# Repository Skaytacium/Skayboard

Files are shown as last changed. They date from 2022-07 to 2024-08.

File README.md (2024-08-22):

# Skayboard

## What?

Its **Skay**tacium's key**board**.

## Why? (I get this one a lot)

Good question.

## Layout?

[Here](http://www.keyboard-layout-editor.com/#/gists/023afb41bbd40c8d3c89d3bae84d59ea).

## Really, why?

I couldn't find a keyboard which had this exact layout (some suggested a 60% + numpad, do you think I'm sensible?).  
I also found the pre-existing PCBs too expensive and the open source ones had goofy layouts.  
I'm jobless, stupid and I regret everything.

## And?

- The `sk` keys are macro keys.
- It uses [QMK](https://qmk.fm/).
- Uses [SK6812 Mini-E](https://cdn-shop.adafruit.com/product-files/4960/4960_SK6812MINI-E_REV02_EN.pdf) LEDs, hand solder them if you want to, connection matrix [here](#connections) (because the name starts with SK).
+ The Skaytacium way to build one would be:
  - C<sup>3</sup>Equalz Tangerines, light green (52g)
  - 5mm acrylic plate
  - Stacked crylic and aluminum (layered)
- It took me ~~2~~ 3 years to make this (check earliest commit) because of the global chip shortage and doomerism.

## Details?

### PCB?
- 2 layer
- 355x107 mm
- AVR (32U4), keeping it as simple as possible.
	+ There is no ESD, overcurrent or surge protection on the PCB. I assume all modern electronic USB ports to compensate for that.
- Pads made for handsoldering.
- Curved traces, because the 90s were cool.
- **Not attached to the case in any way, only to the plate, allows for more customizable mounting options.**
- `svg` and `dxf` files for reference are in `lib/gen`.

#### Renders?
- Front
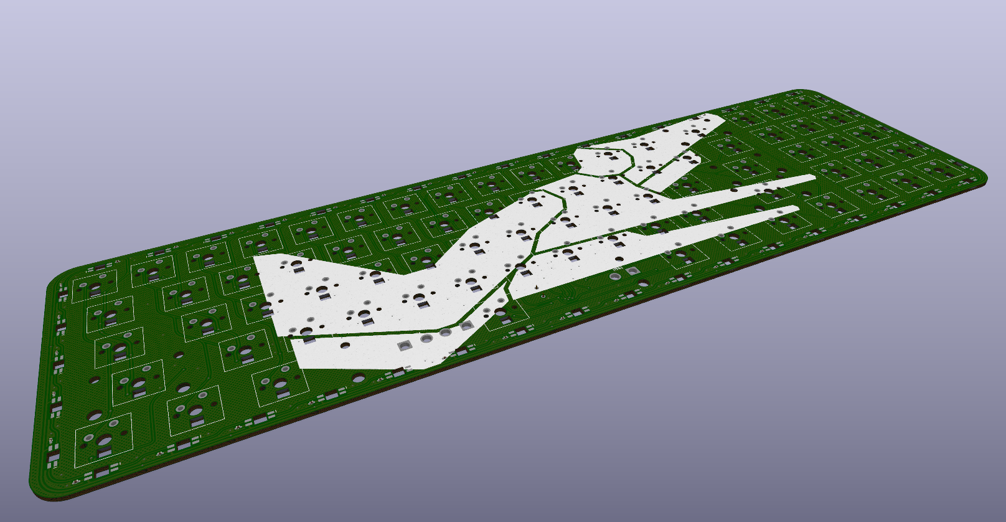
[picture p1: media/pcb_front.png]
pcb front

- Back
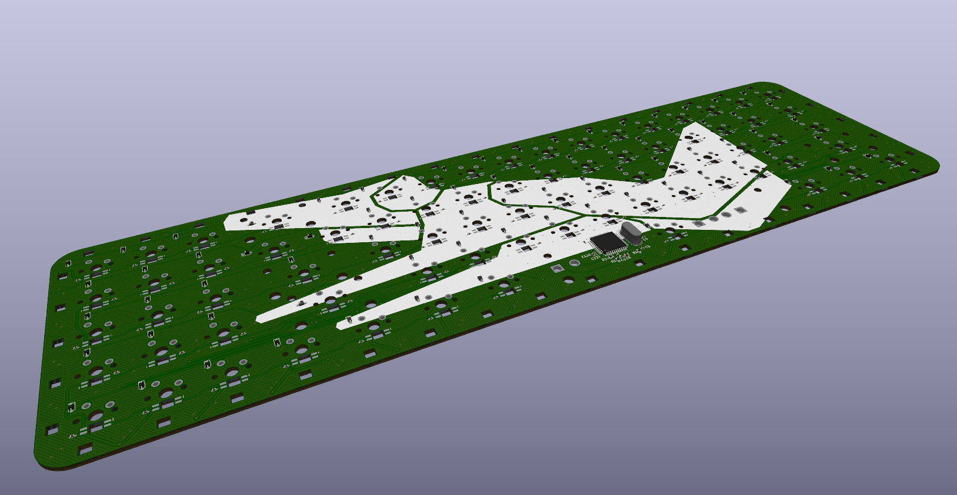
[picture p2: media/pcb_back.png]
pcb back

- Front populated
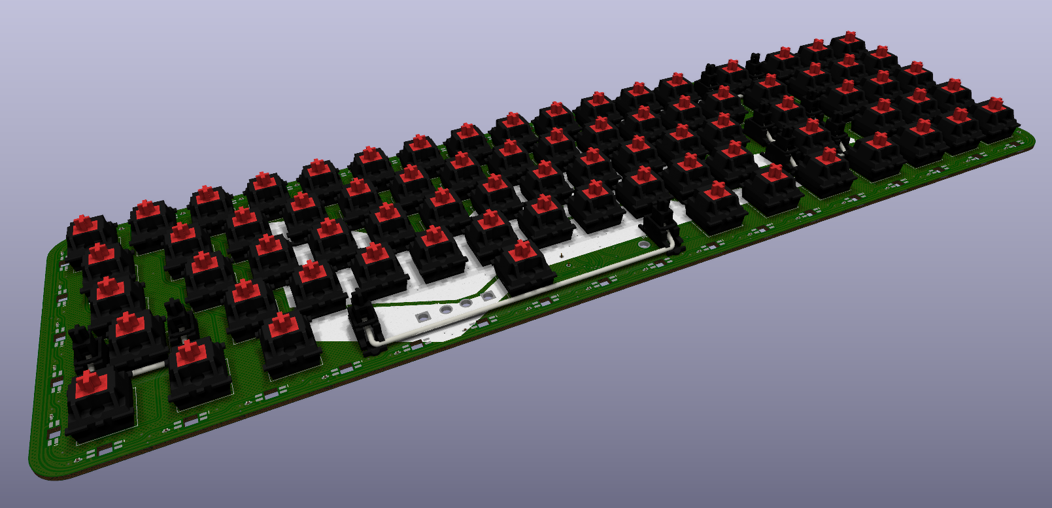
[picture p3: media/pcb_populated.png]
pcb populated


### Plate?
- Desgined for 5mm plates, but can be used for 3mm-5mm.
	+ 1.5mm should also be possible, but it is strongly not recommended to use that.
- Who am I to tell you though, go crazy with it, `dxf` file is in `lib/gen`.

#### Renders?
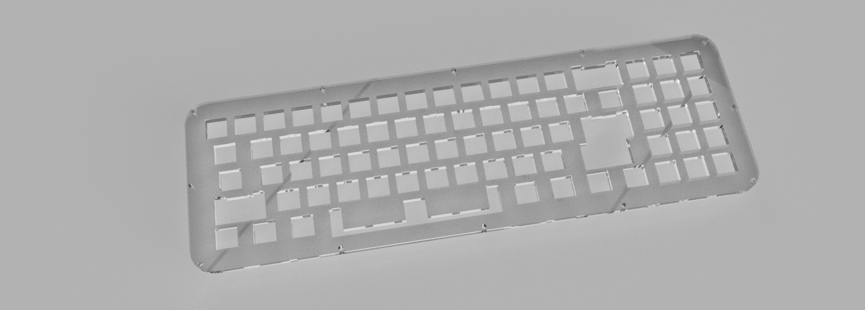
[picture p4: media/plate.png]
plate


### Case?
- Stacked in the following order:
	+ Spacer (L2)
	+ Plate (PCB has no connection to the case)
	+ Spacer (L1)
	+ Spacer (L0)
	+ Case & Logo
- **IMPORTANT:** Spacers L1 and L0 should have atleast 6mm of total height due to the oscillator being an HC49, and that requires 4mm clearance + 1.6mm clearance for PCB thickness.
- **ALSO IMPORTANT:** Either one of spacers L1 or L0 have to be transparent, otherwise you won't be able to see the underglow LEDs (duh). But again, go crazy with it.
- **ALSO SERIOUSLY IMPORTANT:** The `dxf` files do not contain holes for threading, even though the renders show that, you'll have to choose your method of connection, i.e. glue or self-drilled screws. 
- Case & Logo are a single layer since the logo is just an inverse of the case cutout.
- All `dxf` files are in `lib/gen`.

#### Renders?
- Case & Logo
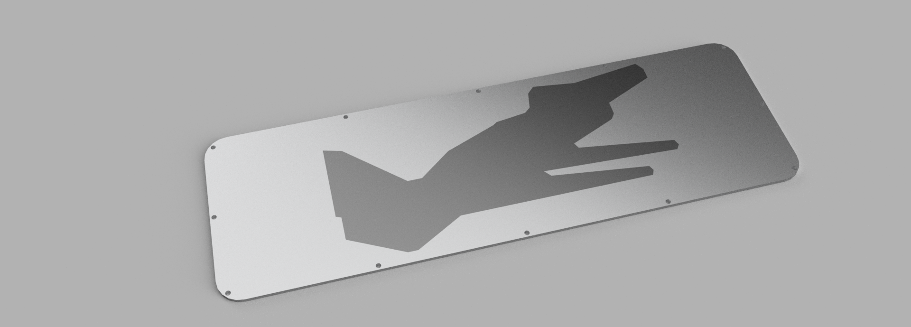
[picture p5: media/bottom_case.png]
case and logo

- Full case
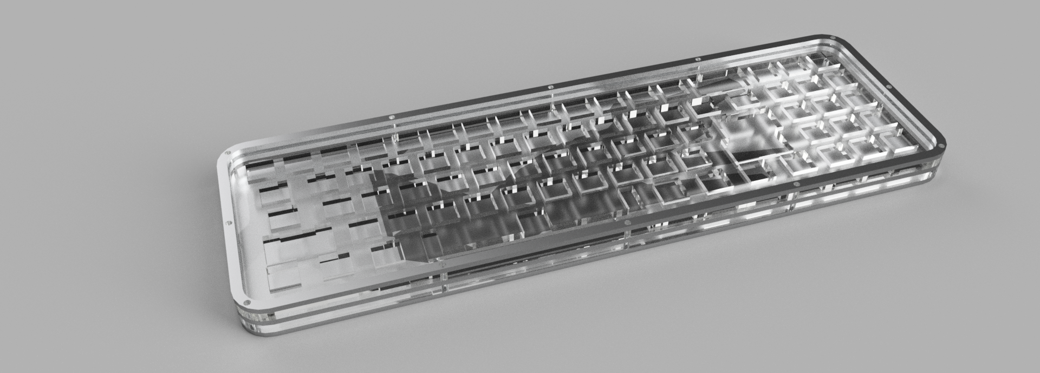
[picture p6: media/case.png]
case


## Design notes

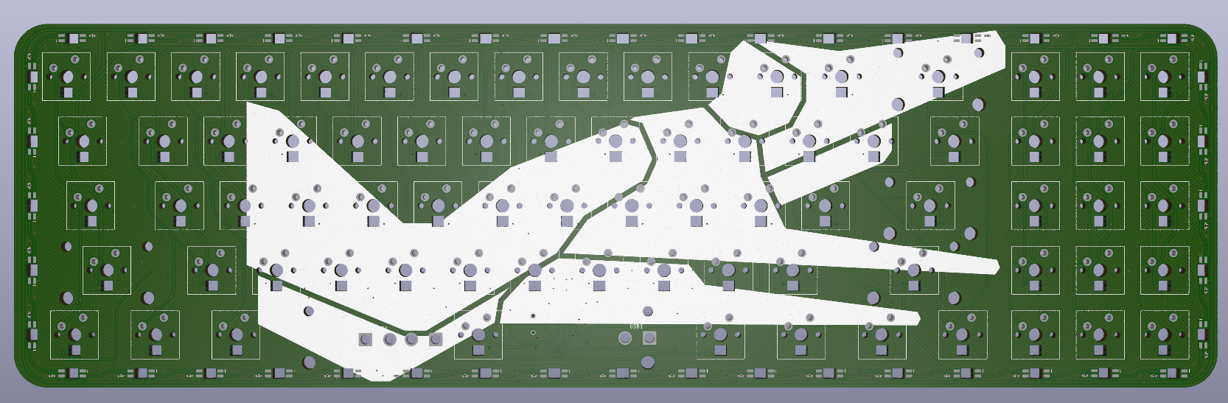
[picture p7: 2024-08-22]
media/pcb_top.png

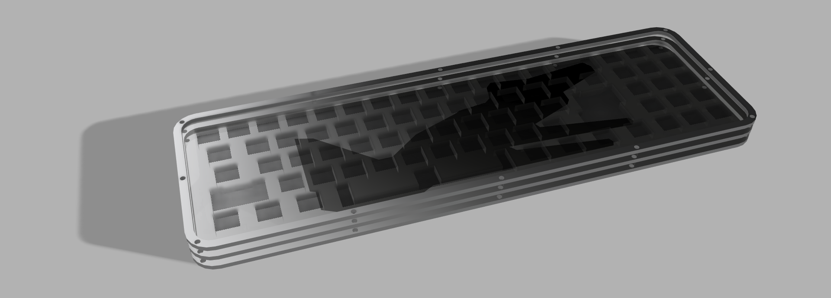
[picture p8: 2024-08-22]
media/case_front.png

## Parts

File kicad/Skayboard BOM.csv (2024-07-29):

Reference | Value | Datasheet | Footprint | Qty | DNP
C1,C6,C7,C8,C9,C10,C11,C12,C13,C14,C15,C16,C17,C18,C19,C20,C21,C22,C23,C24,C25,C26,C27,C28,C29,C30,C31,C32,C33,C34,C35,C36,C37,C38,C39,C40,C41,C42,C43,C44,C45,C46,C47,C48,C49,C50,C51,C52,C53,C54,C55,C56,C57,C58,C59,C60,C61,C62,C63,C64,C65,C66,C67,C68,C69,C70,C71,C72,C73,C74,C75,C76,C77,C78,C79,C80,C81,C82,C83,C84,C85,C86,C87,C88,C89,C90,C91,C92,C93,C94,C95,C96,C97,C98,C99,C100,C101,C102,C103,C104,C105,C106,C107,C108,C109,C110,C111,C112,C113,C114,C115,C116,C117,C118,C119,C120,C121,C122,C123,C124,C125,C126,C127,C128 | 100nF | ~ | Capacitor_SMD:C_0402_1005Metric_Pad0.74x0.62mm_HandSolder | 124
C2,C4 | 22pF | ~ | Capacitor_SMD:C_0402_1005Metric_Pad0.74x0.62mm_HandSolder | 2
C3 | 1uF | ~ | Capacitor_SMD:C_0603_1608Metric_Pad1.08x0.95mm_HandSolder | 1
C5 | 10uF | ~ | Capacitor_SMD:C_0603_1608Metric_Pad1.08x0.95mm_HandSolder | 1
D1,D2,D3,D4,D5,D6,D7,D8,D9,D10,D11,D12,D13,D14,D15,D16,D17,D18,D19,D20,D21,D22,D23,D24,D25,D26,D27,D28,D29,D30,D31,D32,D33,D34,D35,D36,D37,D38,D39,D40,D41,D42,D43,D44,D45,D46,D47,D48,D49,D50,D51,D52,D53,D54,D55,D56,D57,D58,D59,D60,D61,D62,D63,D64,D65,D66,D67,D68,D69,D70,D71,D72,D73,D74,D75,D76 | 1N4148WS | https://www.vishay.com/docs/85751/1n4148ws.pdf | Diode_SMD:D_SOD-323_HandSoldering | 76
LED1,LED2,LED3,LED4,LED5,LED6,LED7,LED8,LED9,LED10,LED11,LED12,LED13,LED14,LED15,LED16,LED17,LED18,LED19,LED20,LED21,LED22,LED23,LED24,LED25,LED26,LED27,LED28,LED29,LED30,LED31,LED32,LED33,LED34,LED35,LED36,LED37,LED38,LED39,LED40,LED41,LED42,LED43,LED44,LED45,LED46,LED47,LED48,LED49,LED50,LED51,LED52,LED53,LED54,LED55,LED56,LED57,LED58,LED59,LED60,LED61,LED62,LED63,LED64,LED65,LED66,LED67,LED68,LED69,LED70,LED71,LED72,LED73,LED74,LED75,LED76,LED77,LED78,LED79,LED80,LED81,LED82,LED83,LED84,LED85,LED86,LED87,LED88,LED89,LED90,LED91,LED92,LED93,LED94,LED95,LED96,LED97,LED98,LED99,LED100,LED101,LED102,LED103,LED104,LED105,LED106,LED107,LED108,LED109,LED110,LED111,LED112,LED113,LED114,LED115,LED116,LED117,LED118,LED119,LED120 | SK6812MINI-E | https://cdn-shop.adafruit.com/product-files/4960/4960_SK6812MINI-E_REV02_EN.pdf | Skayboard:SK6812MINI-E | 120 | DNP
POWER1,RST1,USB1 | Conn_01x02 | ~ | Connector_Wire:SolderWire-2.5sqmm_1x02_P7.2mm_D2.4mm_OD3.6mm | 3 | DNP
R1 | 10K | ~ | Resistor_SMD:R_0603_1608Metric_Pad0.98x0.95mm_HandSolder | 1
R2,R3 | 22 | ~ | Resistor_SMD:R_0603_1608Metric_Pad0.98x0.95mm_HandSolder | 2
U1 | ATmega32U4-A | http://ww1.microchip.com/downloads/en/DeviceDoc/Atmel-7766-8-bit-AVR-ATmega16U4-32U4_Datasheet.pdf | Package_QFP:TQFP-44_10x10mm_P0.8mm | 1
Y1 | 16MHz | ~ | Crystal:Crystal_HC49-U_Vertical | 1

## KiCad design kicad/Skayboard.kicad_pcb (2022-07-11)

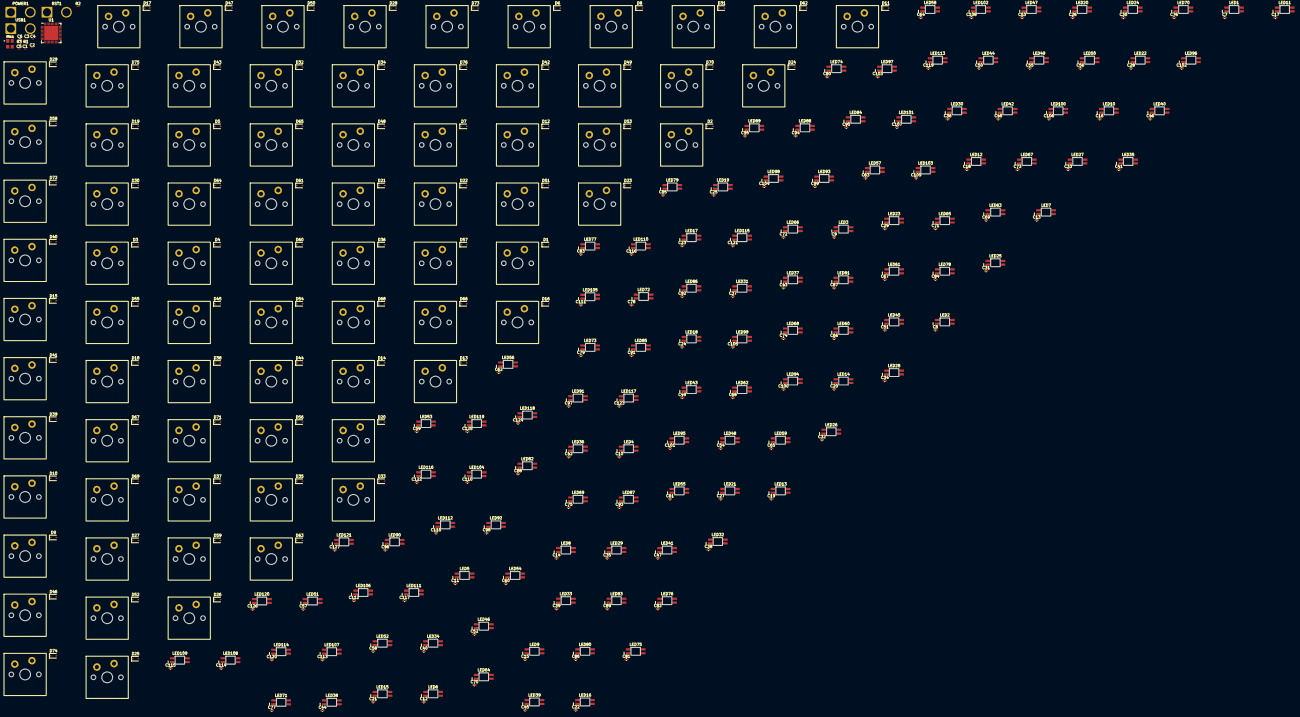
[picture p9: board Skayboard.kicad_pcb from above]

Board: 2 copper layers, 408 parts (0 on the bottom side), 153 nets, no tracks yet.

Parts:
C1, C2, C3, C4: 22pF; C_01005_0402Metric
C5: 100nF; C_01005_0402Metric
C6, C7, C8, C9, C10, C11, C12, C13, C14, C15, C16, C17, C18, C19, C20, C21, C22, C23, C24, C25, C26, C27, C28, C29, C30, C31, C32, C33, C34, C35, C36, C37, C38, C39, C40, C41, C42, C43, C44, C45, C46, C47, C48, C49, C50, C51, C52, C53, C54, C55, C56, C57, C58, C59, C60, C61, C62, C63, C64, C65, C66, C67, C68, C69, C70, C71, C72, C73, C74, C75, C76, C77, C78, C79, C80, C81, C82, C83, C84, C85, C86, C87, C88, C89, C90, C91, C92, C93, C94, C95, C96, C97, C98, C99, C100, C101, C102, C103, C104, C105, C106, C107, C108, C109, C110, C111, C112, C113, C114, C115, C116, C117, C118, C119, C120, C121, C122, C123, C124, C125, C126, C127: 100nF; C_0402_1005Metric
D1, D2, D3, D4, D5, D6, D7, D8, D9, D10, D11, D12, D13, D14, D15, D16, D17, D18, D19, D20, D21, D22, D23, D24, D25, D26, D27, D28, D29, D30, D31, D32, D33, D34, D35, D36, D37, D38, D39, D40, D41, D42, D43, D44, D45, D46, D47, D48, D49, D50, D51, D52, D53, D54, D55, D56, D57, D58, D59, D60, D61, D62, D63, D64, D65, D66, D67, D68, D69, D70, D71, D72, D73, D74, D75, D76: 1N4148WS; D_SOD-323
LED1, LED2, LED3, LED4, LED5, LED6, LED7, LED8, LED9, LED10, LED11, LED12, LED13, LED14, LED15, LED16, LED17, LED18, LED19, LED20, LED21, LED22, LED23, LED24, LED25, LED26, LED27, LED28, LED29, LED30, LED31, LED32, LED33, LED34, LED35, LED36, LED37, LED38, LED39, LED40, LED41, LED42, LED43, LED44, LED45, LED46, LED47, LED48, LED49, LED50, LED51, LED52, LED53, LED54, LED55, LED56, LED57, LED58, LED59, LED60, LED61, LED62, LED63, LED64, LED65, LED66, LED67, LED68, LED69, LED70, LED71, LED72, LED73, LED74, LED75, LED76, LED77, LED78, LED79, LED80, LED81, LED82, LED83, LED84, LED85, LED86, LED87, LED88, LED89, LED90, LED91, LED92, LED93, LED94, LED95, LED96, LED97, LED98, LED99, LED100, LED101, LED102, LED103, LED104, LED105, LED106, LED107, LED108, LED109, LED110, LED111, LED112, LED113, LED114, LED115, LED116, LED117, LED118, LED119, LED120, LED121: SK6812MINI-E
MX1, MX2, MX3, MX4, MX5, MX6, MX7, MX8, MX9, MX10, MX11, MX12, MX13, MX14, MX15, MX16, MX17, MX18, MX19, MX20, MX21, MX22, MX23, MX24, MX25, MX26, MX27, MX28, MX29, MX30, MX31, MX32, MX33, MX34, MX35, MX36, MX37, MX38, MX39, MX40, MX41, MX42, MX43, MX44, MX45, MX46, MX47, MX48, MX49, MX50, MX51, MX52, MX53, MX54, MX55, MX56, MX57, MX58, MX59, MX60, MX61, MX62, MX63, MX64, MX65, MX66, MX67, MX68, MX69, MX70, MX71, MX72, MX73, MX74, MX75, MX76: MX
POWER1: Conn_01x02; SolderWire-2.5sqmm_1x02_P7.2mm_D2.4mm_OD3.6mm
R1, R2: 22; R_0201_0603Metric
R3: 10K; R_0201_0603Metric
RST1: Conn_01x02; SolderWire-2.5sqmm_1x02_P7.2mm_D2.4mm_OD3.6mm
U1: ATmega32U4-M; QFN-44-1EP_7x7mm_P0.5mm_EP5.2x5.2mm
USB1: Conn_01x02; SolderWire-2.5sqmm_1x02_P7.2mm_D2.4mm_OD3.6mm
XTAL1: X322516MLB4SI; OSC_X322516MLB4SI

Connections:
/0/DIN: LED10.2 (DOUT), LED11.4 (DIN)
/1/DIN: LED1.2 (DOUT), LED2.4 (DIN)
/1/DOUT: LED2.2 (DOUT), LED3.4 (DIN)
/2/DOUT: LED3.2 (DOUT), LED4.4 (DIN)
/3/DOUT: LED4.2 (DOUT), LED5.4 (DIN)
/4/DOUT: LED5.2 (DOUT), LED6.4 (DIN)
/5/DOUT: LED6.2 (DOUT), LED7.4 (DIN)
/6/DOUT: LED7.2 (DOUT), LED8.4 (DIN)
/7/DOUT: LED8.2 (DOUT), LED9.4 (DIN)
/8/DOUT: LED9.2 (DOUT), LED10.4 (DIN)
/"/DIN: LED49.2 (DOUT), LED50.4 (DIN)
/"/DOUT: LED50.2 (DOUT), LED52.4 (DIN)
/,/DIN: LED67.4 (DIN), LED68.2 (DOUT)
/,/DOUT: LED66.4 (DIN), LED67.2 (DOUT)
/-/DIN: LED11.2 (DOUT), LED12.4 (DIN)
/-/DOUT: LED12.2 (DOUT), LED13.4 (DIN)
/./DIN: LED68.4 (DIN), LED69.2 (DOUT)
/;/DIN: LED48.2 (DOUT), LED49.4 (DIN)
/=/DOUT: LED13.2 (DOUT), LED14.4 (DIN)
/A/DIN: LED40.4 (DIN), LED80.2 (DOUT)
/A/DOUT: LED40.2 (DOUT), LED41.4 (DIN)
/B Slash/DIN: LED33.4 (DIN), LED34.2 (DOUT)
/B Slash/DOUT: LED32.4 (DIN), LED33.2 (DOUT)
/B/DIN: LED64.4 (DIN), LED65.2 (DOUT)
/B/DOUT: LED63.4 (DIN), LED64.2 (DOUT)
/Bksp/DOUT: LED14.2 (DOUT), LED15.4 (DIN)
/C/DIN: LED62.4 (DIN), LED63.2 (DOUT)
/C/DOUT: LED61.4 (DIN), LED62.2 (DOUT)
/COL^{0}: MX1.1 (COL), MX18.1 (COL), MX35.1 (COL), MX51.1 (COL), MX66.1 (COL), U1.18 (PD0)
/COL^{1}: MX2.1 (COL), MX19.1 (COL), MX36.1 (COL), MX52.1 (COL), MX67.1 (COL), U1.19 (PD1)
/COL^{2}: MX3.1 (COL), MX20.1 (COL), MX37.1 (COL), MX53.1 (COL), MX68.1 (COL), U1.20 (PD2)
/COL^{3}: MX4.1 (COL), MX21.1 (COL), MX38.1 (COL), MX54.1 (COL), U1.21 (PD3)
/COL^{4}: MX5.1 (COL), MX22.1 (COL), MX39.1 (COL), MX55.1 (COL), U1.22 (PD5)
/COL^{5}: MX6.1 (COL), MX23.1 (COL), MX40.1 (COL), MX56.1 (COL), MX69.1 (COL), U1.25 (PD4)
/COL^{6}: MX7.1 (COL), MX24.1 (COL), MX41.1 (COL), MX57.1 (COL), U1.37 (PF6)
/COL^{7}: MX8.1 (COL), MX25.1 (COL), MX42.1 (COL), MX58.1 (COL), U1.38 (PF5)
/COL^{8}: MX9.1 (COL), MX26.1 (COL), MX43.1 (COL), MX59.1 (COL), U1.39 (PF4)
/COL^{9}: MX10.1 (COL), MX27.1 (COL), MX44.1 (COL), MX60.1 (COL), MX70.1 (COL), U1.40 (PF1)
/COL^{10}: MX11.1 (COL), MX28.1 (COL), MX45.1 (COL), MX61.1 (COL), MX71.1 (COL), U1.41 (PF0)
/COL^{11}: MX12.1 (COL), MX29.1 (COL), MX46.1 (COL), MX62.1 (COL), MX72.1 (COL), U1.1 (PE6)
/COL^{12}: MX13.1 (COL), MX30.1 (COL), MX47.1 (COL), U1.8 (PB0)
/COL^{13}: MX14.1 (COL), MX31.1 (COL), MX73.1 (COL), U1.9 (PB1)
/COL^{14}: MX15.1 (COL), MX32.1 (COL), MX48.1 (COL), MX63.1 (COL), MX74.1 (COL), U1.10 (PB2)
/COL^{15}: MX16.1 (COL), MX33.1 (COL), MX49.1 (COL), MX64.1 (COL), MX75.1 (COL), U1.11 (PB3)
/COL^{16}: MX17.1 (COL), MX34.1 (COL), MX50.1 (COL), MX65.1 (COL), MX76.1 (COL), U1.12 (PB7)
/Caps/DIN: LED39.2 (DOUT), LED80.4 (DIN)
/D/DIN: LED41.2 (DOUT), LED42.4 (DIN)
/D/DOUT: LED42.2 (DOUT), LED43.4 (DIN)
/Del/DIN: LED34.4 (DIN), LED35.2 (DOUT)
/Down/DIN: LED100.2 (DOUT), LED101.4 (DIN)
/Down/DOUT: LED101.2 (DOUT), LED103.4 (DIN)
/E/DIN: LED23.4 (DIN), LED24.2 (DOUT)
/E/DOUT: LED22.4 (DIN), LED23.2 (DOUT)
/End/DIN: LED35.4 (DIN), LED37.2 (DOUT)
/Enter/DOUT: LED52.2 (DOUT), LED54.4 (DIN)
/Esc/DIN: LED1.4 (DIN), LED20.2 (DOUT)
/F Slash/DIN: LED69.4 (DIN), LED70.2 (DOUT)
/F/DOUT: LED43.2 (DOUT), LED44.4 (DIN)
/G/DOUT: LED44.2 (DOUT), LED45.4 (DIN)
/H/DOUT: LED45.2 (DOUT), LED46.4 (DIN)
/Home/DIN: LED15.2 (DOUT), LED16.4 (DIN)
/Home/DOUT: LED16.2 (DOUT), LED18.4 (DIN)
/I/DIN: LED28.4 (DIN), LED29.2 (DOUT)
/I/DOUT: LED27.4 (DIN), LED28.2 (DOUT)
/J/DOUT: LED46.2 (DOUT), LED47.4 (DIN)
/K/DOUT: LED47.2 (DOUT), LED48.4 (DIN)
/L Alt/DIN: LED81.2 (DOUT), LED83.4 (DIN)
/L Alt/DOUT: LED83.2 (DOUT), LED87.4 (DIN)
/L Ctrl/DOUT: LED59.2 (DOUT), LED81.4 (DIN)
/L Shift/DIN: LED39.4 (DIN), LED60.2 (DOUT)
/LED: LED59.4 (DIN), U1.26 (PD6)
/Left/DIN: LED99.2 (DOUT), LED100.4 (DIN)
/M/DOUT: LED65.4 (DIN), LED66.2 (DOUT)
/Meta/DIN: LED95.2 (DOUT), LED96.4 (DIN)
/Meta/DOUT: LED96.2 (DOUT), LED99.4 (DIN)
/O/DIN: LED29.4 (DIN), LED30.2 (DOUT)
/P/DIN: LED30.4 (DIN), LED31.2 (DOUT)
/PgDn/DIN: LED37.4 (DIN), LED57.2 (DOUT)
/Q/DIN: LED21.4 (DIN), LED22.2 (DOUT)
/Q/DOUT: LED20.4 (DIN), LED21.2 (DOUT)
/R Alt/DIN: LED87.2 (DOUT), LED94.4 (DIN)
/R Alt/DOUT: LED94.2 (DOUT), LED95.4 (DIN)
/R Shift/DIN: LED70.4 (DIN), LED75.2 (DOUT)
/R/DIN: LED24.4 (DIN), LED25.2 (DOUT)
/ROW^{0}: D1.1 (K), D2.1 (K), D3.1 (K), D4.1 (K), D5.1 (K), D6.1 (K), D7.1 (K), D8.1 (K), D9.1 (K), D10.1 (K), D11.1 (K), D12.1 (K), D13.1 (K), D14.1 (K), D15.1 (K), D16.1 (K), D17.1 (K), U1.29 (PB5)
/ROW^{1}: D18.1 (K), D19.1 (K), D20.1 (K), D21.1 (K), D22.1 (K), D23.1 (K), D24.1 (K), D25.1 (K), D26.1 (K), D27.1 (K), D28.1 (K), D29.1 (K), D30.1 (K), D31.1 (K), D32.1 (K), D33.1 (K), D34.1 (K), U1.30 (PB6)
/ROW^{2}: D36.1 (K), D37.1 (K), D38.1 (K), D39.1 (K), D40.1 (K), D41.1 (K), D42.1 (K), D43.1 (K), D44.1 (K), D45.1 (K), D46.1 (K), D47.1 (K), D48.1 (K), D49.1 (K), D50.1 (K), D66.1 (K), U1.31 (PC6)
/ROW^{3}: D35.1 (K), D52.1 (K), D53.1 (K), D54.1 (K), D55.1 (K), D56.1 (K), D57.1 (K), D58.1 (K), D59.1 (K), D60.1 (K), D61.1 (K), D62.1 (K), D63.1 (K), D64.1 (K), D65.1 (K), U1.32 (PC7)
/ROW^{4}: D51.1 (K), D67.1 (K), D68.1 (K), D69.1 (K), D70.1 (K), D71.1 (K), D72.1 (K), D73.1 (K), D74.1 (K), D75.1 (K), D76.1 (K), U1.33 (~HWB/PE2)
/Right/DOUT: LED78.4 (DIN), LED103.2 (DOUT)
/SK1/DOUT: LED54.2 (DOUT), LED55.4 (DIN)
/SK2/DOUT: LED55.2 (DOUT), LED57.4 (DIN)
/SK4/DIN: LED75.4 (DIN), LED76.2 (DOUT)
/SK5/DOUT: LED76.4 (DIN), LED78.2 (DOUT)
/T/DIN: LED25.4 (DIN), LED26.2 (DOUT)
/U/DOUT: LED26.4 (DIN), LED27.2 (DOUT)
/ULED: LED18.2 (DOUT), LED85.4 (DIN)
/ULED1/DOUT: LED17.4 (DIN), LED85.2 (DOUT)
/ULED2/DOUT: LED17.2 (DOUT), LED19.4 (DIN)
/ULED3/DOUT: LED19.2 (DOUT), LED36.4 (DIN)
/ULED4/DOUT: LED36.2 (DOUT), LED38.4 (DIN)
/ULED5/DOUT: LED38.2 (DOUT), LED71.4 (DIN)
/ULED6/DIN: LED51.2 (DOUT), LED53.4 (DIN)
/ULED8/DIN: LED51.4 (DIN), LED71.2 (DOUT)
/ULED10/DIN: LED53.2 (DOUT), LED56.4 (DIN)
/ULED10/DOUT: LED56.2 (DOUT), LED58.4 (DIN)
/ULED11/DIN: LED72.2 (DOUT), LED73.4 (DIN)
/ULED11/DOUT: LED73.2 (DOUT), LED74.4 (DIN)
/ULED12/DIN: LED74.2 (DOUT), LED77.4 (DIN)
/ULED12/DOUT: LED77.2 (DOUT), LED104.4 (DIN)
/ULED13/DIN: LED72.4 (DIN), LED79.2 (DOUT)
/ULED14/DIN: LED58.2 (DOUT), LED79.4 (DIN)
/ULED16/DIN: LED92.4 (DIN), LED105.2 (DOUT)
/ULED16/DOUT: LED91.4 (DIN), LED92.2 (DOUT)
/ULED17/DIN: LED97.4 (DIN), LED98.2 (DOUT)
/ULED17/DOUT: LED97.2 (DOUT), LED105.4 (DIN)
/ULED19/DOUT: LED102.4 (DIN), LED104.2 (DOUT)
/ULED20/DOUT: LED90.4 (DIN), LED91.2 (DOUT)
/ULED21/DOUT: LED98.4 (DIN), LED102.2 (DOUT)
/ULED23/DOUT: LED89.4 (DIN), LED90.2 (DOUT)
/ULED24/DIN: LED84.4 (DIN), LED86.2 (DOUT)
/ULED24/DOUT: LED82.4 (DIN), LED84.2 (DOUT)
/ULED25/DIN: LED88.4 (DIN), LED93.2 (DOUT)
/ULED25/DOUT: LED86.4 (DIN), LED88.2 (DOUT)
/ULED26/DOUT: LED82.2 (DOUT), LED106.4 (DIN)
/ULED27/DIN: LED89.2 (DOUT), LED93.4 (DIN)
/ULED29/DOUT: LED106.2 (DOUT), LED121.4 (DIN)
/ULED31/DIN: LED113.2 (DOUT), LED114.4 (DIN)
/ULED31/DOUT: LED114.2 (DOUT), LED120.4 (DIN)
/ULED32/DIN: LED116.4 (DIN), LED120.2 (DOUT)
/ULED32/DOUT: LED116.2 (DOUT), LED117.4 (DIN)
/ULED34/DIN: LED118.2 (DOUT), LED119.4 (DIN)
/ULED35/DIN: LED112.2 (DOUT), LED113.4 (DIN)
/ULED36/DIN: LED117.2 (DOUT), LED118.4 (DIN)
/ULED38/DIN: LED111.2 (DOUT), LED112.4 (DIN)
/ULED39/DIN: LED107.2 (DOUT), LED108.4 (DIN)
/ULED39/DOUT: LED108.2 (DOUT), LED109.4 (DIN)
/ULED40/DIN: LED109.2 (DOUT), LED110.4 (DIN)
/ULED40/DOUT: LED110.2 (DOUT), LED115.4 (DIN)
/ULED41/DIN: LED107.4 (DIN), LED121.2 (DOUT)
/ULED42/DOUT: LED111.4 (DIN), LED115.2 (DOUT)
/X/DOUT: LED60.4 (DIN), LED61.2 (DOUT)
/[/DIN: LED31.4 (DIN), LED32.2 (DOUT)
GND: C1.1, C2.1, C3.1, C4.1, C5.1, C6.1, C7.1, C8.1, C9.1, C10.1, C11.1, C12.1, C13.1, C14.1, C15.1, C16.1, C17.1, C18.1, C19.1, C20.1, C21.1, C22.1, C23.1, C24.1, C25.1, C26.1, C27.1, C28.1, C29.1, C30.1, C31.1, C32.1, C33.1, C34.1, C35.1, C36.1, C37.1, C38.1, C39.1, C40.1, C41.1, C42.1, C43.1, C44.1, C45.1, C46.1, C47.1, C48.1, C49.1, C50.1, C51.1, C52.1, C53.1, C54.1, C55.1, C56.1, C57.1, C58.1, C59.1, C60.1, C61.1, C62.1, C63.1, C64.1, C65.1, C66.1, C67.1, C68.1, C69.1, C70.1, C71.1, C72.1, C73.1, C74.1, C75.1, C76.1, C77.1, C78.1, C79.1, C80.1, C81.1, C82.1, C83.1, C84.1, C85.1, C86.1, C87.1, C88.1, C89.1, C90.1, C91.1, C92.1, C93.1, C94.1, C95.1, C96.1, C97.1, C98.1, C99.1, C100.1, C101.1, C102.1, C103.1, C104.1, C105.1, C106.1, C107.1, C108.1, C109.1, C110.1, C111.1, C112.1, C113.1, C114.1, C115.1, C116.1, C117.1, C118.1, C119.1, C120.1, C121.1, C122.1, C123.1, C124.1, C125.1, C126.1, C127.1, LED1.3 (VSS), LED2.3 (VSS), LED3.3 (VSS), LED4.3 (VSS), LED5.3 (VSS), LED6.3 (VSS), LED7.3 (VSS), LED8.3 (VSS), LED9.3 (VSS), LED10.3 (VSS), LED11.3 (VSS), LED12.3 (VSS), LED13.3 (VSS), LED14.3 (VSS), LED15.3 (VSS), LED16.3 (VSS), LED17.3 (VSS), LED18.3 (VSS), LED19.3 (VSS), LED20.3 (VSS), LED21.3 (VSS), LED22.3 (VSS), LED23.3 (VSS), LED24.3 (VSS), LED25.3 (VSS), LED26.3 (VSS), LED27.3 (VSS), LED28.3 (VSS), LED29.3 (VSS), LED30.3 (VSS), LED31.3 (VSS), LED32.3 (VSS), LED33.3 (VSS), LED34.3 (VSS), LED35.3 (VSS), LED36.3 (VSS), LED37.3 (VSS), LED38.3 (VSS), LED39.3 (VSS), LED40.3 (VSS), LED41.3 (VSS), LED42.3 (VSS), LED43.3 (VSS), LED44.3 (VSS), LED45.3 (VSS), LED46.3 (VSS), LED47.3 (VSS), LED48.3 (VSS), LED49.3 (VSS), LED50.3 (VSS), LED51.3 (VSS), LED52.3 (VSS), LED53.3 (VSS), LED54.3 (VSS), LED55.3 (VSS), LED56.3 (VSS), LED57.3 (VSS), LED58.3 (VSS), LED59.3 (VSS), LED60.3 (VSS), LED61.3 (VSS), LED62.3 (VSS), LED63.3 (VSS), LED64.3 (VSS), LED65.3 (VSS), LED66.3 (VSS), LED67.3 (VSS), LED68.3 (VSS), LED69.3 (VSS), LED70.3 (VSS), LED71.3 (VSS), LED72.3 (VSS), LED73.3 (VSS), LED74.3 (VSS), LED75.3 (VSS), LED76.3 (VSS), LED77.3 (VSS), LED78.3 (VSS), LED79.3 (VSS), LED80.3 (VSS), LED81.3 (VSS), LED82.3 (VSS), LED83.3 (VSS), LED84.3 (VSS), LED85.3 (VSS), LED86.3 (VSS), LED87.3 (VSS), LED88.3 (VSS), LED89.3 (VSS), LED90.3 (VSS), LED91.3 (VSS), LED92.3 (VSS), LED93.3 (VSS), LED94.3 (VSS), LED95.3 (VSS), LED96.3 (VSS), LED97.3 (VSS), LED98.3 (VSS), LED99.3 (VSS), LED100.3 (VSS), LED101.3 (VSS), LED102.3 (VSS), LED103.3 (VSS), LED104.3 (VSS), LED105.3 (VSS), LED106.3 (VSS), LED107.3 (VSS), LED108.3 (VSS), LED109.3 (VSS), LED110.3 (VSS), LED111.3 (VSS), LED112.3 (VSS), LED113.3 (VSS), LED114.3 (VSS), LED115.3 (VSS), LED116.3 (VSS), LED117.3 (VSS), LED118.3 (VSS), LED119.3 (VSS), LED120.3 (VSS), LED121.3 (VSS), POWER1.2, RST1.2, U1.5 (UGND), U1.15 (GND), U1.23 (GND), U1.35 (GND), U1.43 (GND), U1.45 (GND), XTAL1.2, XTAL1.4
unnamed: C1.2, U1.17 (XTAL1), XTAL1.1
unnamed: C2.2, U1.16 (XTAL2), XTAL1.3
unnamed: C3.2, R1.1, U1.4 (D+)
unnamed: C4.2, R2.1, U1.3 (D-)
unnamed: C5.2, U1.42 (AREF)
unnamed: C6.2, R3.1, RST1.1, U1.13 (~RESET)
unnamed: R1.2, USB1.1
unnamed: R2.2, USB1.2
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

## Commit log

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2020-10-27 Better directory tree and README
    [Skayboard.PrjPcb, SkayboardRev2.PcbDoc, SkayboardRev2.SchDoc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]
2020-10-28 Keys arranged, partially labelled
    [Skayboard.PrjPcb, SkayboardRev2.PcbDoc, SkayboardRev2.SchDoc]
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2020-10-30 Added new footprint and changed symbol
    [Skayboard.PcbLib, Skayboard.PrjPcb, Skayboard.SchLib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]
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2020-10-30 Changed BOM and schematic symbol
    [Skayboard.SchLib]
2020-10-30 Changed symbol, minor changes
    [Skayboard.SchLib]
2020-10-30 Added nets to the component
    [Skayboard.PcbLib, Skayboard.SchLib]
2020-10-31 Switches placed and routed, pcb outline created.
    [Skayboard.PrjPcb, SkayboardRev2.PcbDoc, SkayboardRev2.SchDoc]
2020-11-01 Cleaned history and updated schematic
    [Skayboard.PrjPcb, Skayboard.SchLib, SkayboardRev2.PcbDoc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]
2020-11-03 PCB lib inspected, pad pin numbers changed to non conflicting ones.
    [Skayboard.PcbLib, Skayboard.SchLib, SkayboardRev2.PcbDoc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]
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2020-11-03 Symbol-footprint link sorted out (next time set symbol library type to 'standard' not 'mechanical', otherwise footprint linking will not be possible)
    [Skayboard.PrjPcb, Skayboard.SchLib, SkayboardRev2.PcbDoc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]
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2020-11-03 switches reposition in pcb, errors removed
    [Skayboard.SchLib, SkayboardRev2.PcbDoc, SkayboardRev2.SchDoc]
2020-11-03 Changed plate, removed history, updated schematic and PCB
    [Skayboard.PcbLib, Skayboard.PrjPcb, Skayboard.SchLib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]
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2020-11-05 Wiring R/C done and designator fix
    [SkayboardRev2.PcbDoc]
2020-11-05 Major changes to LED wiring for easy routing
    [SkayboardRev2.SchDoc]
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2020-11-05 Major changes to PCB
    Footprint has been updated and diode is on the
    bottom side now. PCB wiring is being redone and
    updating schematics and footprints constantly.
    [Skayboard.PcbLib, Skayboard.SchLib, SkayboardRev2.PcbDoc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]
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2020-11-12 Major changes
    Added rows to the PCB, mirrored the LEDs for easy connection and added a new schematic symbol in the library for the mirrored LED. Added some VCC connections.
    [Skayboard.PcbLib, Skayboard.SchLib, SkayboardRev2.PcbDoc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]
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2020-11-15 Four layers enabled, ground plane added, microcontroller placed
    [SkayboardRev2.PcbDoc, SkayboardRev2.SchDoc]
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2020-12-14 Too lazy to note changes, but deleted history and rev3 has begun
    [Skayboard.PcbLib, Skayboard.PrjPcb, SkayboardRev2.PcbDoc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]
2020-12-14 Few changes
    -Rev 3 started completely, Rev 2 is removed from project.
    -Cleaned up schematic (changed a few key wirings, TODO: uC pinout).
    -Finished tracing the LEDs, starting columns/rows
    [SkayboardRev3.PcbDoc]
2020-12-14 Big changes
    -Wired rows and columns
    -Changed stabilizer footprint
    -Removed stupid bulk
    [Skayboard.PcbLib, Skayboard.PrjPcb, SkayboardRev3.PcbDoc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]
2020-12-14 Connected VCC, might have to redo due to uC stuff
    [SkayboardRev3.PcbDoc]
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2020-12-15 Decent changes
    -Removed columns
    -Changed footprints
    -Don't want to start over again
    [Skayboard.PcbLib, Skayboard.SchLib, SkayboardRev3.PcbDoc]
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2020-12-15 Diodes placed, first row of LEDs almost done
    [Skayboard.kicad_pcb, Stabilizer_Cherry_MX_2u.FCStd, Stabilizer_Cherry_MX_3u.FCStd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]
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2020-12-16 Major changes
    - Cleaned up wiring
    - Added a new schematic symbol and PCB symbol for an oscillator so that I can order a cheaper part.
    - PCB Designing is pain
    - Started uC wiring
    [Skayboard.PcbLib, Skayboard.SchLib, SkayboardRev3.PcbDoc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]
2020-12-16 Major Changes
    -Almost finished uC wiring
    (Need to rotate uC, add oscillator, start column/row connections)
    -Enhanced footprints further
    -Made USB connections
    -Finally
    [Skayboard.PcbLib, Skayboard.SchLib, SkayboardRev3.PcbDoc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]
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2020-12-16 Columns 0 to 5 wired, doing 12 to 16.
    [SkayboardRev3.PcbDoc, SkayboardRev3.SchDoc]
2020-12-16 JUST TWO GODDAMN COLUMS LEFT AND SID IS LIKE "COMMITCOMMITCOMMIT"
    [SkayboardRev3.PcbDoc, SkayboardRev3.SchDoc]
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2020-12-17 Decent changes
    - Finished LED wiring
    - Updating schematic and doing rows
    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
    [Skayboard.PcbLib, SkayboardRev3.PcbDoc]
2020-12-17 Almost
    -Schematic update needed
    -Underglow, soon
    -Oscillator (still haven't done it)
    [SkayboardRev3.PcbDoc, SkayboardRev3.SchDoc]
2020-12-18 Updates
    -Cleaned up bunch of traces
    -Better via placement
    -VCC connected to USB
    -Nets cleared
    TODO: Update schematic (very petty), oscillator, underglow
    [SkayboardRev3.PcbDoc, SkayboardRev3.SchDoc]
2020-12-18 Crystal placed, logo and credits made a little bigger, row nets assigned.
    [Skayboard.PcbLib, Skayboard.SchLib, SkayboardRev3.PcbDoc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]
2020-12-18 Major changes
    - Added test points for unused pins
    - Cleaned oscillator because NNNI wired it
    - Made a little space for underglow
    - Sent JLCPCB an email
    [SkayboardRev3.PcbDoc]
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2020-12-26 Major changes
    -Midway through VCC wiring
    -About to start on underglow
    [SkayboardRev4.PcbDoc]
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2020-12-26 Bug fixes?
    [SkayboardRev4.PcbDoc]
2020-12-26 Major changes
    -Started normal LED footprint
    -Rough underglow positioning done
    -Added silkscreen
    -Few things to be changed
    [Skayboard.PcbLib, SkayboardRev4.PcbDoc]
2020-12-27 Big changes
    -Made new footprint
    -Squashed some bugs
    -Started underglow
    -Schematic updated
    -Added some keepouts
    -Cleaned stuff up
    [Skayboard.PcbLib, Skayboard.SchLib, SkayboardRev4.PcbDoc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]
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2020-12-27 Decent changes
    -Finished equation for placing LEDs
    -One coordinate for each side done
    -Saved project
    [Skayboard.PrjPcb, SkayboardRev4.PcbDoc]
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2020-12-28 Major changes
    -Ground plane v0.6.9 done
    -Cleaned up a lot of DRC errors
    -Cleared some shorts in footprints
    -Removed crap silkscreen
    -Better LED pads
    -Added ground vias
    -Almost there
    TODO: Clear up more DRC
    [Skayboard.PcbLib]
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2020-12-30 Major changes
    - First build done, gerber outputs look fine
    - Cleaned up designators
    - Better schematic library
    - About to start work with the Pick and place and BOM files
    - Getting there very soon
    [LED v0.step, LED v1.step, LED v2.f3d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]
2020-12-31 Major changes
    -Added an OutputJob file to automate production
    -Adding version numbers to each entry
    -Cleaned folder directory
    -Outputs can now be found in the Revision folder, e.g. Rev4
    -P&P and BOM files will be handled seperately
    [LED v0.step, LED v1.step, LED v2.f3d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]
2020-12-31 Decent changes
    -Better output job
    -Better BOM
    TODO: Make BOM and P&P JLCPCB compatible
    [Bill of Materials-SkayboardRev4.xlsx, Pick Place for SkayboardRev4.csv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]
2021-01-01 Rev5...
    I'm too tired to put more commit messages here, rev5 is starting, this
    time I will add versions and all that good shit, plus everything will be
    integrated in altium so that my brain doesn't melt trying to place
    reference offsets in Excel.
    Sanity is also down to 5%
    [Bill of Materials-SkayboardRev4.xlsx, Pick Place for SkayboardRev4.csv, Skayboard.PcbLib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]
2021-01-01 Cleaned up way too much stuff
    [Skayboard.kicad_pcb, Skayboard.sch, Stabilizer_Cherry_MX_2u.FCStd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]
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2021-05-21 Oh boy here we go again aka Rev6
    [SK6812 Mini-E.SchDoc, Skayboard.PrjPcb, Skayboard.SchDoc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]
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2021-05-25 6.2.0; Massive changes
    - Redesigned the entire library thing
    - Started schematic again
    - Cleaned MCU schematic
    - Cleaned SchLib
    - Cleaned PcbLib
    - Better pinouts
    - Less warnings
    - No errors
    - Better design
    Jesus
    [Key.SchDoc, SK6812 Mini-E.SchDoc, SK6812.SchDoc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]
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2021-05-28 6.2.0; Decent
    Better schematic, starting work on PCB and other weird stuff.
    [Skayboard.PrjPcb, Skayboard.SchDoc]
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2021-07-27 Started PCB, Finished LED tracing
    Bunch of additiosn
    Schematic redesigned because i messed up
    [Skayboard.SchDoc]
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2022-06-07 fix: adds link for LEDs in README
    [Skayboard.kicad_sch]
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2024-05-25 fix: removes altium
    [Bill of Materials-Skayboard.xlsx, LED.step, Pick Place for Skayboard.csv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]
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
